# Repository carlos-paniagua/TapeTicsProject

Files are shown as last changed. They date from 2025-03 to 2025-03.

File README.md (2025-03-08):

# Tape-Tics: A Flexible and Modular Vibrotactile Feedback System for Rapid Prototyping
Carlos Paniagua, Hiroki Ota, Yutaro Hirao, Monica Perusquia-Hernandez, Hideaki Uchiyama, Kiyoshi Kiyokawa

This repository contains the hardware and software design files for TapeTics

## Content
Hardware/ -  Circuit Information \
src/ - Source code open with platformIO \
GUI/ - GUI controller using Max8 

## Software Version Information
1. Arduino IDE 2.3.2\
   Queue 2,0\
   NimBLE-Arduino 1.4.2\
   FastLED 3.7.3\
   M5Atom 0.1.2\
   M5Stack 2.1.1\
   ArxContainer 0.7.0\
   IRremote 4.4.1\
   ArduinoOSC 0.5.1\
   MAX30100lib 1.2.1
2. Max 8.6.4
3. Python 3.12\
   Bleak \
   pythonosc
4. VScode
5. PlatfromIO

## Component list

| Parts | Quantity | Value | Cost  ($) |
|:---|---:|:---|---:|
| Chip Capacitor 0.1μf |3 | [CC0603KRX7R9BB104](https://jlcpcb.com/partdetail/Yageo-CC0603KRX7R9BB104/C14663)  |0.0063|
| Chip Capacitor 10μf|2 | [CL10A106KP8NNNC](https://jlcpcb.com/partdetail/20411-CL10A106KP8NNNC/C19702) |0.01|
| Diode|1 | [1N4001W](https://jlcpcb.com/partdetail/Yongyutai-1N4001W/C2944152)|0.0052|
| RGB-LED  |  1 | [WS2812B-V5/W](https://jlcpcb.com/partdetail/Worldsemi-WS2812B_V5W/C2874885) |0.0762|
| Neopixel IC| 1 | [WS2811](https://jlcpcb.com/partdetail/Worldsemi-WS2811/C114581) |0.033|
| Vibrating Motor|1 | [LCM1027A2445F](https://jlcpcb.com/partdetail/Leader-LCM1027A2445F/C2759984) |0.30|
| Chip Resistor 33Ω| 2 | [0603WAF330JT5E](https://jlcpcb.com/partdetail/23867-0603WAF330JT5E/C23140) |0.002|
| Chip Resistor 100Ω |  1 | [0603WAF1000T5E](https://jlcpcb.com/partdetail/23502-0603WAF1000T5E/C22775) |0.001 |
| Photocoupler |1 | [TLP627(TP1,F)](https://jlcpcb.com/partdetail/Toshiba-TLP627_TP1_F/C30336) | 0.48 |
| Voltage Regulator 16V to 5V| 1 | [SPX3819M5-L-5-0/TR](https://jlcpcb.com/partdetail/MaxLinear-SPX3819M5_L_5_0TR/C13417) |0.1463|
| Voltage Regulator 16V to 3.3V  |1 | [SPX3819M5-L-3-3/TR](https://jlcpcb.com/partdetail/Maxlinear-SPX3819M5_L_3_3TR/C9055) |0.0828|

## Presented Conferences
[MVE 2024](https://ken.ieice.org/ken/paper/20240315DcCd/)\
[VRSJ 2024](https://conference.vrsj.org/ac2024/program/doc/1G-23.pdf)\
[IEEE VR 2025](https://ieeevr.org/2025/program/posters/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)\
[AHs 2025](https://augmented-humans.org/program/)

## Teaser Video (IEEE VR 2025)
youtube (https://youtu.be/rIjlwakAgLE)

## Aknowledgements
[Nara Institute of Science and Technology](https://www.naist.jp/en/)\
[Cybernetics and Reality Engineering (CARE) Laboratory](https://carelab.info/en/)\
Hiroki Ota\
Yutaro Hirao\
Monica Perusquia-Hernandez\
Hideaki Uchiyama\
Kiyoshi Kiyokawa

naist

care

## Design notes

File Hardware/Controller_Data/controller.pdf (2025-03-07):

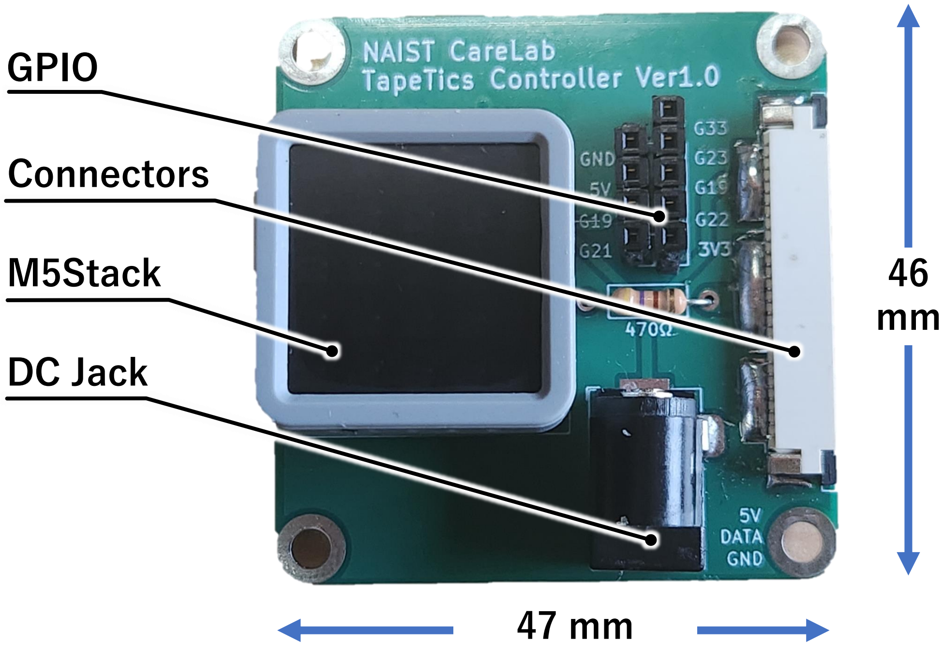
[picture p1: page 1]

46
mm

### 47 mm

Connectors

GPIO

M5Stack

DC Jack

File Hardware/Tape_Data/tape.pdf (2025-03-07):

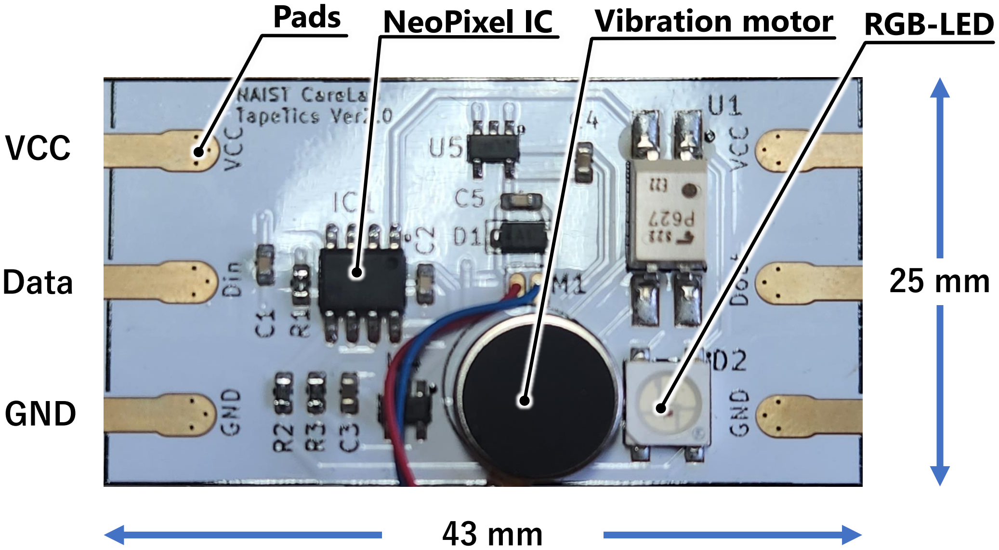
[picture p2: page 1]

Data

VCC

GND

### 25 mm

### 43 mm

Pads | NeoPixel IC | Vibration motor RGB-LED

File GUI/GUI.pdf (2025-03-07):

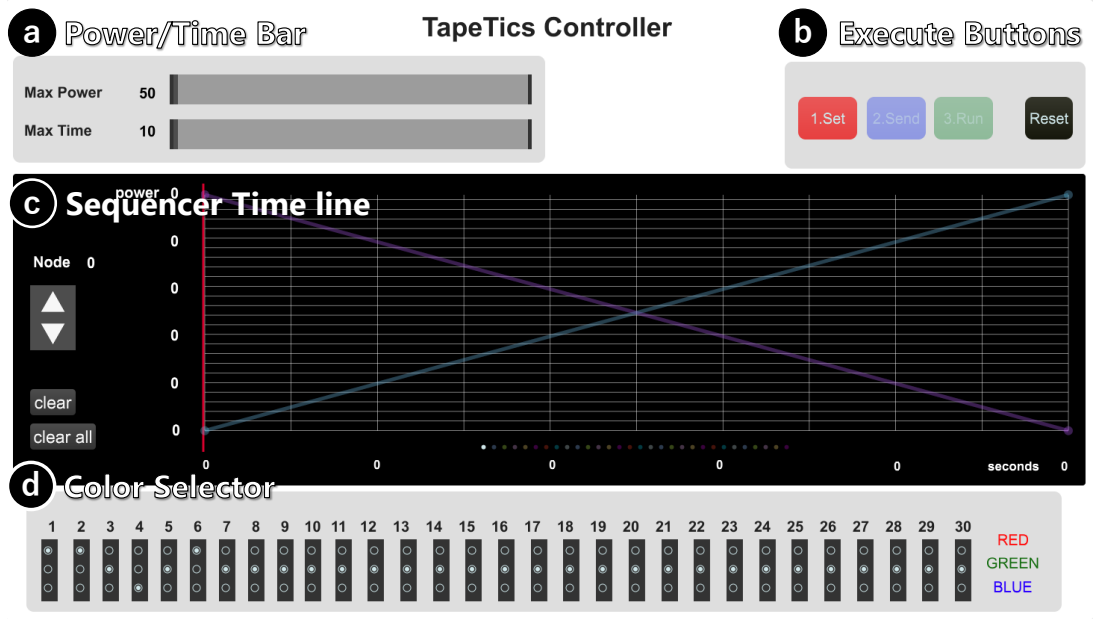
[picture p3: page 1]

Sequencer Time line

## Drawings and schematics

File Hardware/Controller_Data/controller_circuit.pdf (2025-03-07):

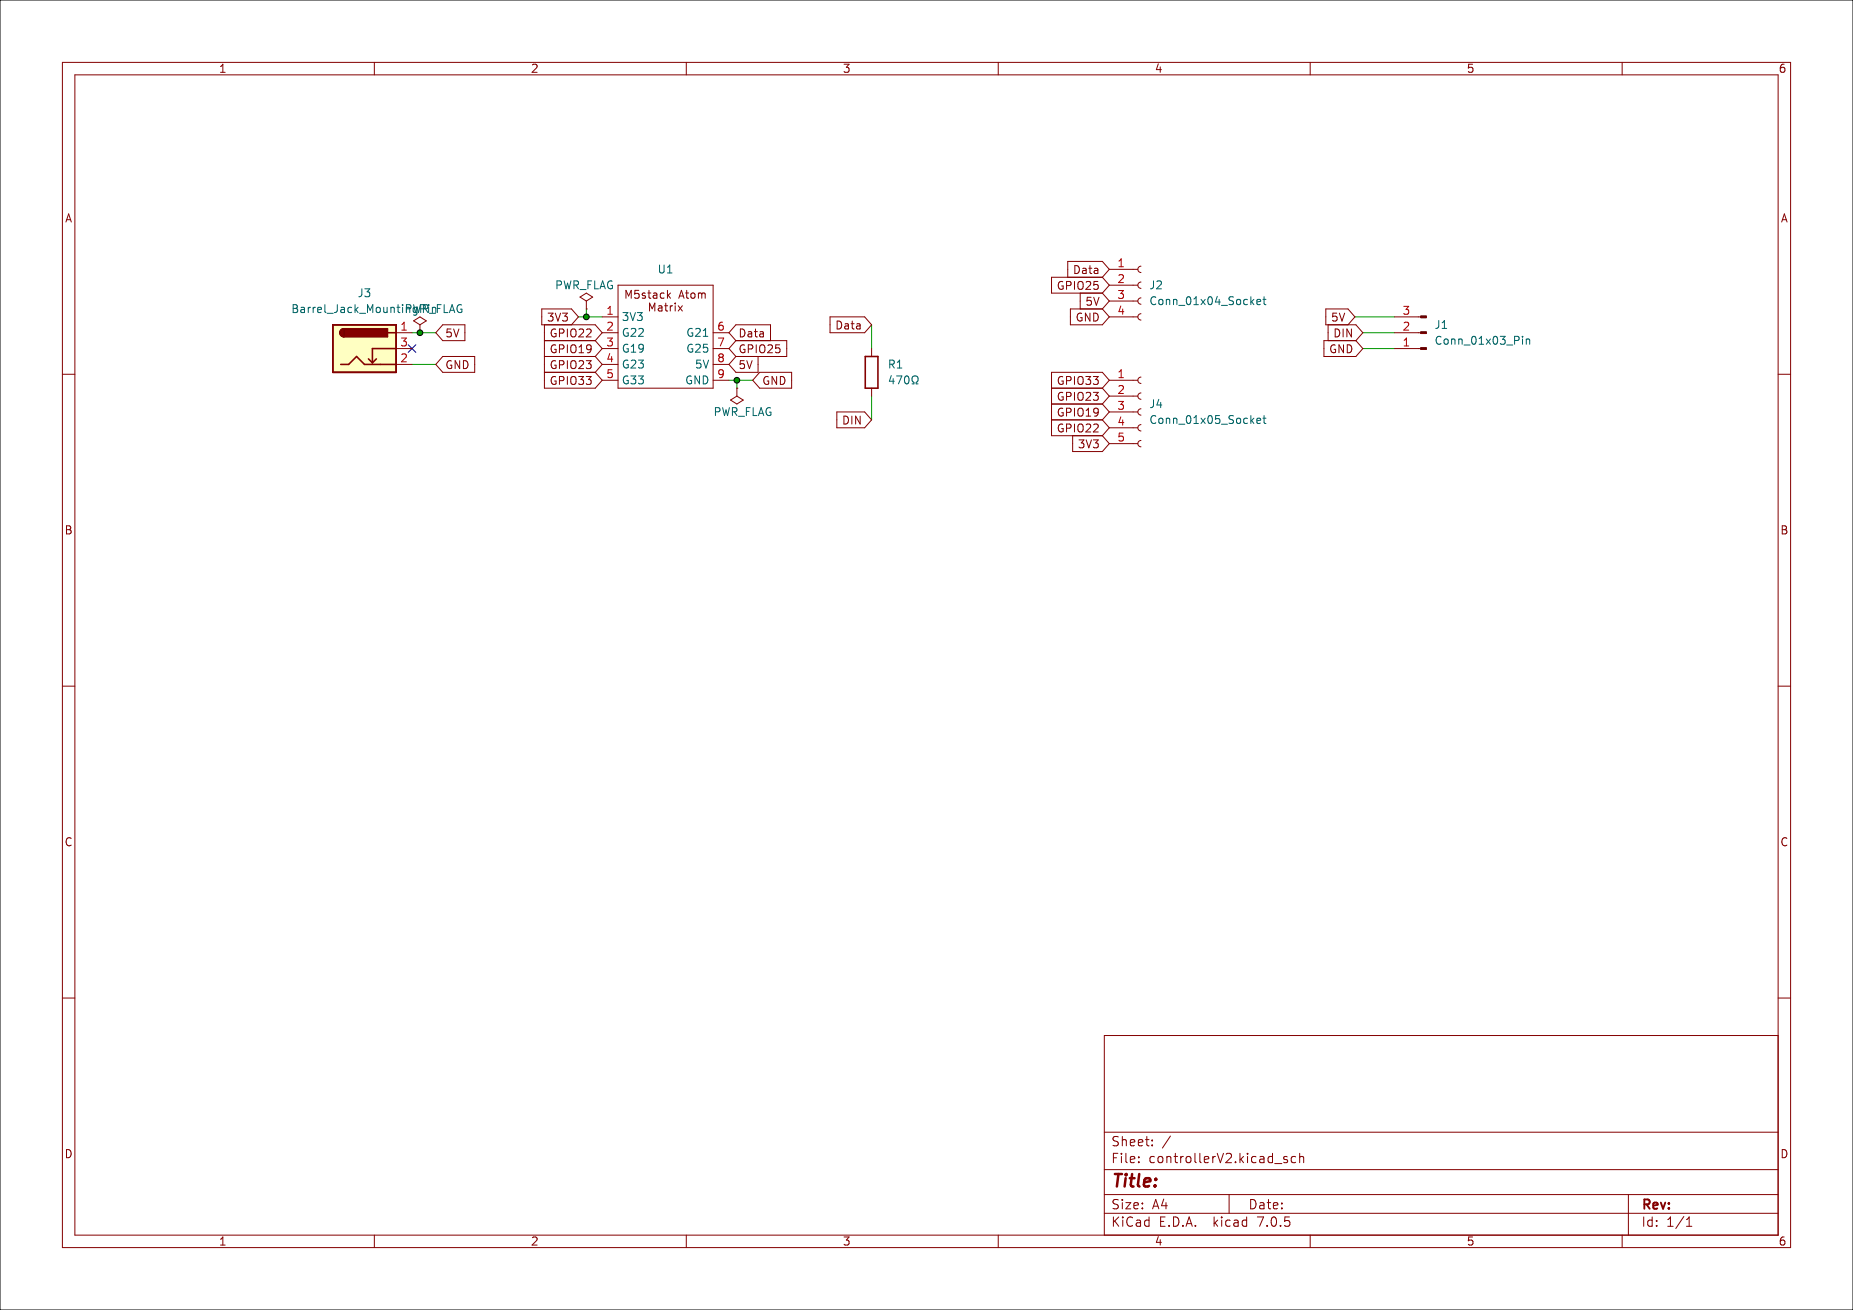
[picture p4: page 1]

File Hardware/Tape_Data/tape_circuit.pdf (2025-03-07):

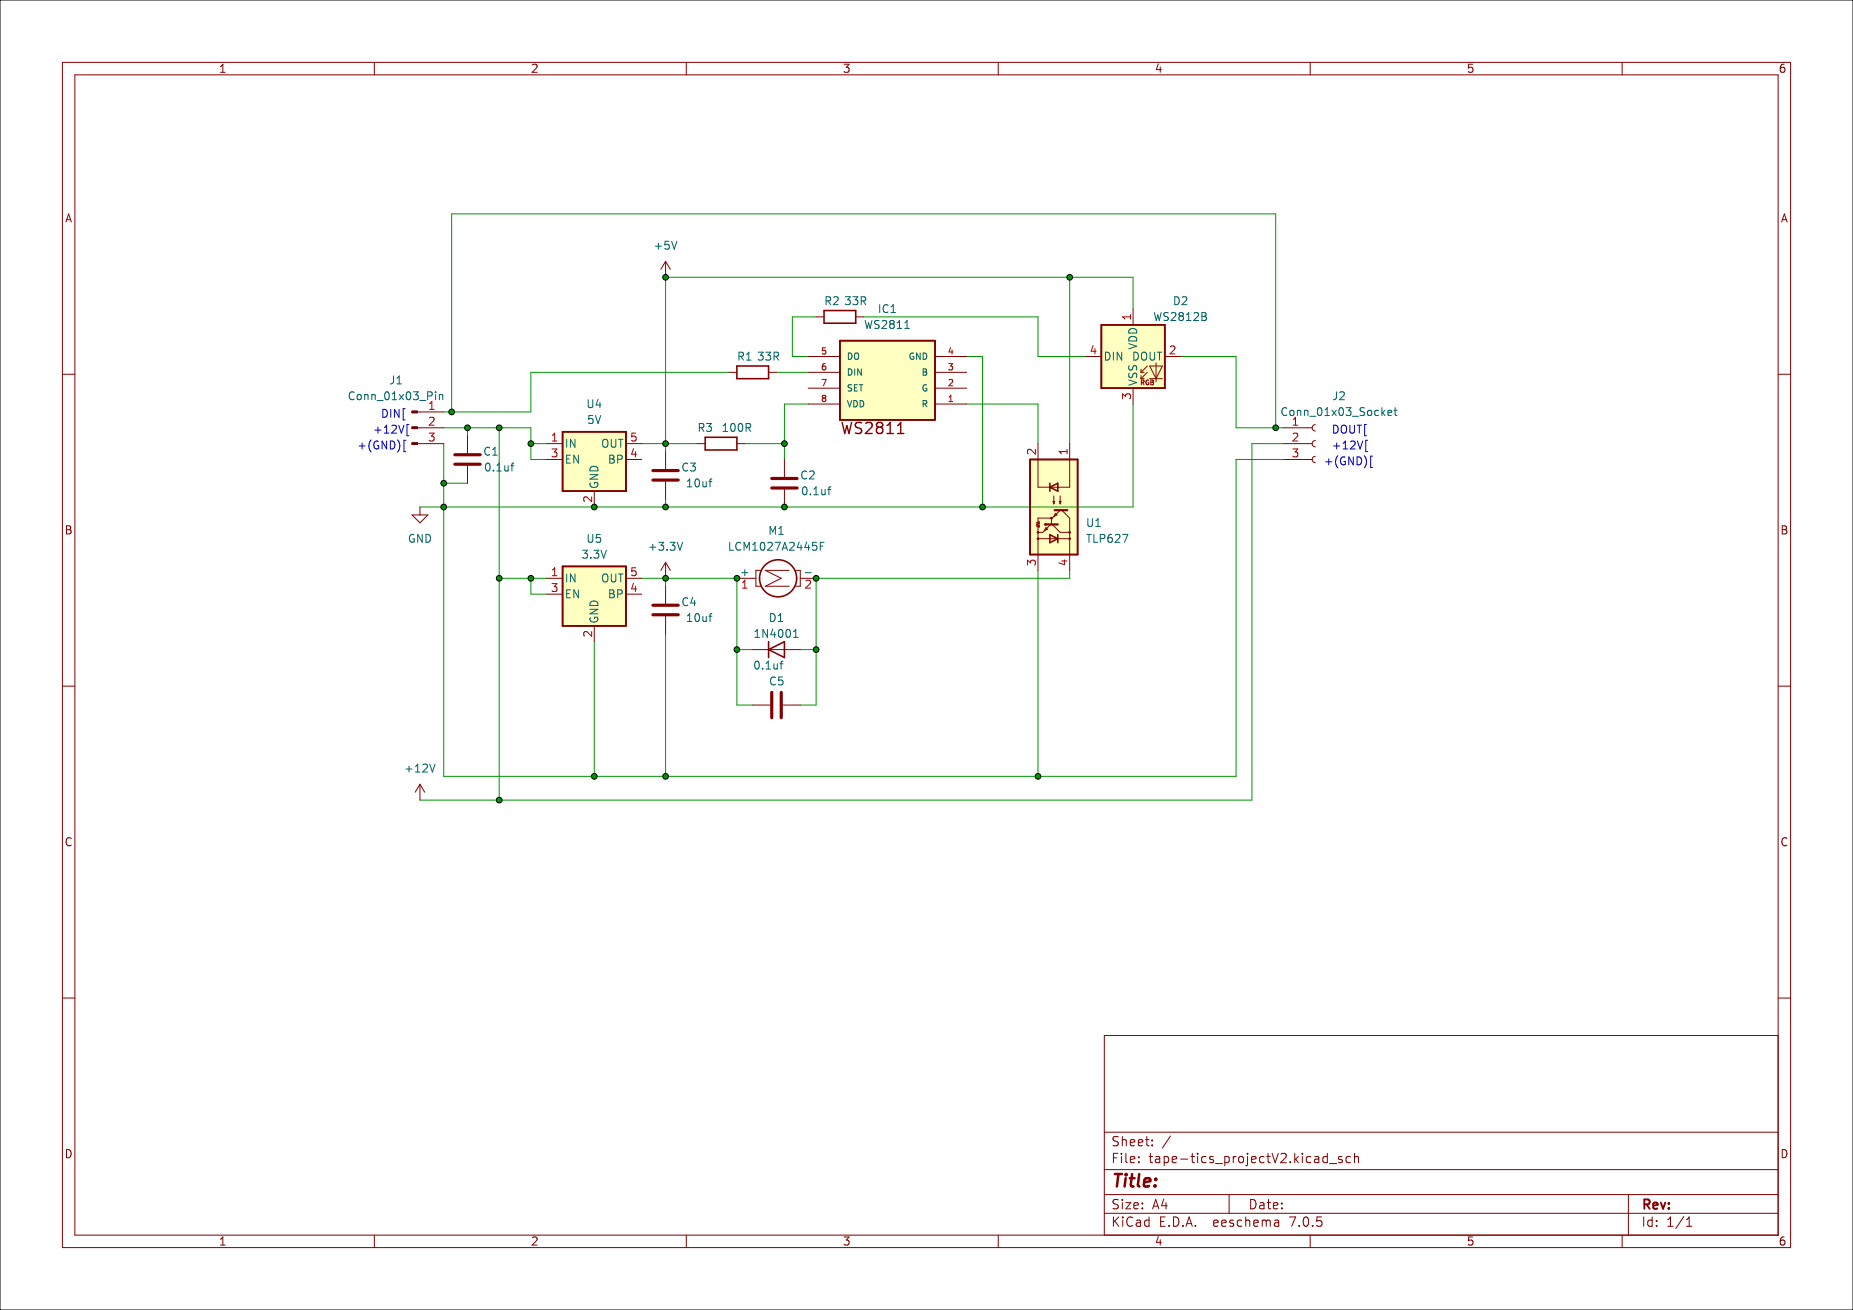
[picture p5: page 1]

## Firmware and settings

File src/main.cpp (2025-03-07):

#include <M5Atom.h>

#define USE_BLE
// #define USE_OSC

// #define DEVICE_TEST
// #ifdef DEVICE_TEST_2

// #deifne USE_OTHER_FUNCTIONS
#define USE_SERIAL_COMMAND
// #define SOUND_MODE
// #define IR_MODE
// #define MUSCLE_MODE
// #define HEART_MODE

int preset_time = 10000;
int steps = 0;

void ledOnSingle(int i);
void ledOn();
String getSerialCommand();

void addMessageToQueue(String command);
void processQueueTask(void *pvParameters);

#ifdef USE_BLE
void handleBLECommand(std::string value);
void processBLETask(void *pvParameters);
#endif // USE_BLE

void setRGB(String s);
void setAllRGB(String s);
void printRGB();

#ifdef IR_MODE
#include <IRremote.h>
int receiverPin = 32;
void IRsensor();
void handleIRCommand(unsigned long command);
#endif

#ifdef MUSCLE_MODE
int EMG_PIN = 33;    // GPIO pin where MyoWare 2.0 sensor is connected
// int THRESHOLD = 500; // Threshold value to detect muscle contraction
void MuscleMode();
#endif

#ifdef HEART_MODE
#include "MAX30100.h"
#define SAMPLING_RATE   (MAX30100_SAMPRATE_100HZ)
#define IR_LED_CURRENT  (MAX30100_LED_CURR_24MA)
#define RED_LED_CURRENT (MAX30100_LED_CURR_27_1MA)
#define PULSE_WIDTH     (MAX30100_SPC_PW_1600US_16BITS)
#define HIGHRES_MODE    (false)
MAX30100 sensor; 
void HeartMode();
#endif

// 追加関数
#ifdef USE_OTHER_FUNCTIONS
void initializeHBM();
void SoundMode();
void shake();
void MuscleMode();
void HeartBeatMode();
void onBeatDetected();
#endif

// アニメーション
void waveAnimation();
void randomAnimation();
void shockAnimation();

// メッセージキューの定義
////////////////////////////////////////////////////////////////////
#include <cppQueue.h>

cppQueue messageQueue(sizeof(String), 1000, FIFO, false); // FIFOキューの初期化

// LED
///////////////////////////////////////////////////////////////////////
#include <FastLED.h>
#include <Wire.h>

#define PIN 22
#define NUMMAX 60
#define NUMSETS 20
#define NUMPIXELS (NUMMAX * 2)
#define LED_TYPE WS2812
#define COLOR_ORDER RGB
#define BRIGHTNESS 255

#define LED_COLOR_GREEN (0x001B00)  // LEDのカラーコード 緑
#define LED_COLOR_RED (0xff0000)    // LEDのカラーコード 赤
#define LED_COLOR_YELLOW (0xffff00) // LEDのカラーコード 赤
#define LED_COLOR_OFF (0x000000)    // LEDのカラーコード 黒

CRGB leds[NUMPIXELS];
int power[NUMMAX]; // セットごとのパワーの配列
int red[NUMMAX];   // セットごとの赤の配列
int green[NUMMAX]; // セットごとの緑の配列
int blue[NUMMAX];  // セットごとの青の配列

bool startExecution = false; // ボタンが押されたら true になる

CRGB getPixelColor1(uint8_t power)
{
  return CRGB(power, 0, 0);
}

CRGB getPixelColor2(uint8_t red, uint8_t green, uint8_t blue)
{
  return CRGB(green, red, blue);
}

#ifdef DEVICE_TEST
// デバイス単体試験用変数
float accX, accY, accZ;

// データ収集用
const int sampleRate = 5;  // サンプリング周期 (ms)
const int duration = 5000; // 測定時間 (ms)
const int numSamples = duration / sampleRate;

float accXData[numSamples];
float accYData[numSamples];
float accZData[numSamples];
// RMS値を計算する関数
float calculateRMS(float *data, int size)
{
  float sum = 0;
  for (int i = 0; i < size; i++)
  {
    sum += data[i] * data[i];
  }
  return sqrt(sum / size);
}

#endif

// BLE
///////////////////////////////////////////////////////////////////////
#ifdef USE_BLE
#include <BLEDevice.h>
#include <BLEUtils.h>
#include <BLEServer.h>
#include <BLE2902.h>

String SERVICE_UUID = "12345678-1234-5678-1234-56789abcdef0";        // サービスUUIDのデフォルト値
String CHARACTERISTIC_UUID = "abcdef12-3456-7890-abcd-ef1234567890"; // キャラクタリスティックUUIDのデフォルト値
String BLE_DEVICE_NAME = "Tapetics_Controller";                      // BLEデバイス名のデフォルト値

BLEServer *pServer = NULL;
BLECharacteristic *pCharacteristic = NULL;
bool deviceConnected = false;

class MyServerCallbacks : public BLEServerCallbacks
{
  void onConnect(BLEServer *pServer) override
  {
    Serial.println("Client connected");
    deviceConnected = true;
    if (deviceConnected)
    {
      M5.dis.fillpix(LED_COLOR_GREEN);
    }
  }
  void onDisconnect(BLEServer *pServer) override
  {
    Serial.println("Client disconnected");
    deviceConnected = false;
    BLEDevice::startAdvertising();
    M5.dis.fillpix(LED_COLOR_RED);
  }
};

void sendDataOverBLE(const char *data)
{
  if (deviceConnected && pCharacteristic != NULL)
  {
    pCharacteristic->setValue(data);
    pCharacteristic->notify();
  }
}

void initializeBLE()
{
  BLEDevice::init(BLE_DEVICE_NAME.c_str());

  pServer = BLEDevice::createServer();
  pServer->setCallbacks(new MyServerCallbacks());
  BLEService *pService = pServer->createService(SERVICE_UUID.c_str());

  pCharacteristic = pService->createCharacteristic(
      CHARACTERISTIC_UUID.c_str(),
      BLECharacteristic::PROPERTY_READ |
          BLECharacteristic::PROPERTY_WRITE |
          BLECharacteristic::PROPERTY_NOTIFY |
          BLECharacteristic::PROPERTY_INDICATE);
  pCharacteristic->addDescriptor(new BLE2902());

  pService->start();

  BLEAdvertising *pAdvertising = BLEDevice::getAdvertising();
  pAdvertising->addServiceUUID(SERVICE_UUID.c_str());
  pAdvertising->setScanResponse(true);
  pAdvertising->setMinPreferred(0x12);

  BLEDevice::startAdvertising();

  Serial.println("BLE initialize complete");

  M5.dis.fillpix(LED_COLOR_RED);
}

#endif // USE_BLE

// OSC
///////////////////////////////////////////////////////////////////////
#ifdef USE_OSC
#include <ArduinoOSCWiFi.h>

const char *ssid = "ssid";      // WiFi SSIDを設定
const char *password = "password";   // WiFi パスワードを設定
const IPAddress ip(192, 168, 11, 43);     // デバイスの固定IPアドレス(M5stackのIP)
const IPAddress gateway(192, 168, 11, 1); // ゲートウェイのIPアドレス(ルーターのIP)
const IPAddress subnet(255, 255, 255, 0); // サブネットマスク

// const char *host = "192.168.11.3"; // 送信先のホストIPアドレス(QuestのIP)
const int recv_port = 8001; // 受信ポート番号(M5Stackが受信するポート番号)
// const int send_port = 9001;        // 送信ポート番号

void initializeWifi()
{
  WiFi.disconnect(true, true); // WiFiを無効にしてAP情報を消去
  delay(200);
  WiFi.begin(ssid, password); // WiFiに接続
  delay(200);
  WiFi.config(ip, gateway, subnet); // 固定IPを設定
  delay(200);

  // WiFi接続待ち
  while (WiFi.status() != WL_CONNECTED)
  {
    delay(500);
  }
  Serial.println("WiFi connected"); // WiFi接続成功メッセージ
  Serial.print("WiFi connected, IP = ");
  Serial.println(WiFi.localIP());
  // M5.dis.fillpix(LED_COLOR_YELLOW);
}

void initializeOSC()
{
  // /fingerアドレスに対してサブスクライブ（OSCメッセージ受信の設定）
  OscWiFi.subscribe(recv_port, "/finger", [](const OscMessage &msg){
  String s = msg.getArgAsString(0);

  Serial.println(s);

  int setIndex, pwr, r, g, b;
  int commaIndex = 0;
  int startIdx = 0;
  int commaIdx = s.indexOf(',');

  setIndex = s.substring(startIdx, commaIdx).toInt() - 1;
  startIdx = commaIdx + 1;
  commaIdx = s.indexOf(',', startIdx);
  // 2. pwr
  power[setIndex] = s.substring(startIdx, commaIdx).toInt();
  startIdx = commaIdx + 1;
  commaIdx = s.indexOf(',', startIdx);
  // 3. r
  red[setIndex] = s.substring(startIdx, commaIdx).toInt();
  startIdx = commaIdx + 1;
  commaIdx = s.indexOf(',', startIdx);
  // 4. g
  green[setIndex] = s.substring(startIdx, commaIdx).toInt();
  startIdx = commaIdx + 1;
  commaIdx = s.indexOf(',', startIdx);
  // 5. b
  blue[setIndex] = s.substring(startIdx, commaIdx).toInt();
  startIdx = commaIdx + 1;
  ledOnSingle(setIndex); });
}
#endif // USE_OSC

// メイン処理
///////////////////////////////////////////////////////////////////////////
void setup()
{
  M5.begin(true, false, true); // 本体初期化（UART, I2C, LED）
  M5.IMU.Init();               // IMUを使うとき解除

#ifdef HEART_MODE
  sensor.begin();
#endif

  FastLED.addLeds<LED_TYPE, PIN, COLOR_ORDER>(leds, NUMMAX).setCorrection(TypicalLEDStrip);
  FastLED.setDither(DISABLE_DITHER);

#ifdef USE_BLE
  initializeBLE();
  xTaskCreatePinnedToCore(processBLETask, "BLETask", 4096, NULL, 1, NULL, 1);
#endif // USE_BLE

#ifdef USE_OSC
  initializeWifi();
  initializeOSC();
#endif // USE_OSC

#ifdef IR_MODE
  IrReceiver.begin(receiverPin, true);
#endif

#ifdef DEVICE_TEST_2
  delay(10000);
  Serial.println("Start in 3 sec");
  delay(3000);

  for (int l = 50; l < 256; l = l + 10)
  {
    String rgbCommand = String(l) + String(",0,0,0");
    // String rgbCommand = String("255,0,0,0");
    setAllRGB(rgbCommand);
    delay(3000);

    float rmsAllValues[5]; // 5回分のRMS_Allを保存
    float rmsAllSum = 0.0; // RMS_Allの合計値（平均計算用）

    //  データ収集
    for (int i = 0; i < 5; i++)
    {
      memset(accXData, 0, sizeof(accXData));
      memset(accYData, 0, sizeof(accYData));
      memset(accZData, 0, sizeof(accZData));

      for (int j = 0; j < numSamples; j++)
      {
        M5.IMU.getAccelData(&accX, &accY, &accZ);

        // データを保存
        accXData[j] = accX;
        accYData[j] = accY;
        accZData[j] = accZ;
        delay(sampleRate); // サンプリング間隔
      }

      // RMS値の計算
      // Serial.println("データ収集完了！RMS値を計算します...");
      float rmsX = calculateRMS(accXData, numSamples);
      float rmsY = calculateRMS(accYData, numSamples);
      float rmsZ = calculateRMS(accZData, numSamples);
      float rmsAll = sqrt((rmsX * rmsX) + (rmsY * rmsY) + (rmsZ * rmsZ));

      rmsAllValues[i] = rmsAll;
      rmsAllSum += rmsAll;

      delay(1000);
    }
    // 平均RMSを計算
    float rmsAllAverage = rmsAllSum / 5.0;
    float ms = rmsAllAverage * 9.81;

    // シリアルに結果を送信 (指定形式)
    Serial.printf("%d, %.3f, %.3f, %.3f, %.3f, %.3f, %.3f, %.3f\n",
                  l, rmsAllValues[0], rmsAllValues[1], rmsAllValues[2], rmsAllValues[3], rmsAllValues[4], rmsAllAverage, ms);
    setAllRGB("0,0,0,0");
    delay(2000); // 次のPWM値に進む前に少し待つ
  }
#endif

  // キュー処理タスクを起動
  xTaskCreatePinnedToCore(processQueueTask, "QueueTask", 4096, NULL, 1, NULL, 0);
  Serial.println("Initialize complete");
}

void loop()
{
  M5.update();

#ifdef USE_OSC
  OscWiFi.update();
#endif

#ifdef USE_SERIAL_COMMAND
  if (Serial.available() > 0)
  {
    String s = getSerialCommand();
    if (s.length() > 0) // 空のメッセージを無視
    {
      if (s == "run")
      {
        if (!startExecution) // 初回のみ出力
        {
          startExecution = true;
          // Serial.println("Starting execution of queued messages.");
        }
      }
      else if (s == "wave" || s == "shock" || s == "random" || s == "ir" || s == "muscle" || s == "heart")
      {
        setRGB(s);
      }
      else
      {
        Serial.println(s);

        int setIndex, pwr, r, g, b;
        // メッセージをカンマで分割
        int commaIndex = 0;
        String parameters[5]; // 6つのパラメータを期待
        // String remaining = *msg;
        int startIdx = 0;
        int commaIdx = s.indexOf(',');
        setIndex = s.substring(startIdx, commaIdx).toInt() - 1;
        startIdx = commaIdx + 1;
        commaIdx = s.indexOf(',', startIdx);
        // 2. pwr
        power[setIndex] = s.substring(startIdx, commaIdx).toInt();
        startIdx = commaIdx + 1;
        commaIdx = s.indexOf(',', startIdx);
        // 3. r
        red[setIndex] = s.substring(startIdx, commaIdx).toInt();
        startIdx = commaIdx + 1;
        commaIdx = s.indexOf(',', startIdx);
        // 4. g
        green[setIndex] = s.substring(startIdx, commaIdx).toInt();
        startIdx = commaIdx + 1;
        commaIdx = s.indexOf(',', startIdx);
        // 5. b
        blue[setIndex] = s.substring(startIdx, commaIdx).toInt();
        startIdx = commaIdx + 1;
        ledOnSingle(setIndex);

#ifdef DEVICE_TEST
        Serial.println("start");
        ledOnSingle(setIndex);
        delay(3000);

        float rmsAllValues[5]; // 5回分のRMS_Allを保存
        float rmsAllSum = 0.0; // RMS_Allの合計値（平均計算用）

        //  データ収集
        for (int i = 0; i < 5; i++)
        {
          memset(accXData, 0, sizeof(accXData));
          memset(accYData, 0, sizeof(accYData));
          memset(accZData, 0, sizeof(accZData));

          for (int j = 0; j < numSamples; j++)
          {
            M5.IMU.getAccelData(&accX, &accY, &accZ);

            // データを保存
            accXData[j] = accX;
            accYData[j] = accY;
            accZData[j] = accZ;
            delay(sampleRate); // サンプリング間隔
          }

          // RMS値の計算
          Serial.println("データ収集完了！RMS値を計算します...");
          float rmsX = calculateRMS(accXData, numSamples);
          float rmsY = calculateRMS(accYData, numSamples);
          float rmsZ = calculateRMS(accZData, numSamples);
          float rmsAll = sqrt((rmsX * rmsX) + (rmsY * rmsY) + (rmsZ * rmsZ));

          rmsAllValues[i] = rmsAll;
          rmsAllSum += rmsAll;

          delay(1000);
        }
        // 平均RMSを計算
        float rmsAllAverage = rmsAllSum / 5.0;
        float ms = rmsAllAverage * 9.81;

        // シリアルに結果を送信 (指定形式)
        Serial.printf("%.3f, %.3f, %.3f, %.3f, %.3f, %.3f, %.3f\n",
                      rmsAllValues[0], rmsAllValues[1], rmsAllValues[2], rmsAllValues[3], rmsAllValues[4], rmsAllAverage, ms);
        setAllRGB("0,0,0,0");
        delay(2000); // 次のPWM値に進む前に少し待つ
#endif
      }
    }
  }
#endif

#ifdef IR_MODE
  if (IrReceiver.decode())
  {
    IrReceiver.printIRResultShort(&Serial);
    if (IrReceiver.decodedIRData.decodedRawData == 0xBA45FF00)
    {
      Serial.println("IR Mode");
      IrReceiver.resume();
      IRsensor();
    }
    IrReceiver.resume();
  }

#endif
}

#ifdef USE_BLE
void handleBLECommand(std::string value)
{
  String command = String(value.c_str());
  if (command == "run")
  {
    startExecution = true;
    Serial.println("Starting execution of queued messages.");
  }
  else if (command == "endSend")
  {
    Serial.print("Queue count after endSend: ");
    Serial.println(messageQueue.getCount());
  }
  else if (command == "wave" || command == "shock" || command == "random")
  {
    setRGB(command);
  }
  else
  {
    addMessageToQueue(command);

#ifdef DEVICE_TEST
    // Latency Measurement
    String s = command;
    int setIndex, pwr, r, g, b;
    // メッセージをカンマで分割
    int commaIndex = 0;
    String parameters[5]; // 6つのパラメータを期待
    // String remaining = *msg;
    int startIdx = 0;
    int commaIdx = s.indexOf(',');

    setIndex = s.substring(startIdx, commaIdx).toInt() - 1;
    startIdx = commaIdx + 1;
    commaIdx = s.indexOf(',', startIdx);

    // 2. pwr
    power[setIndex] = s.substring(startIdx, commaIdx).toInt();
    startIdx = commaIdx + 1;
    commaIdx = s.indexOf(',', startIdx);

    // 3. r
    red[setIndex] = s.substring(startIdx, commaIdx).toInt();
    startIdx = commaIdx + 1;
    commaIdx = s.indexOf(',', startIdx);

    // 4. g
    green[setIndex] = s.substring(startIdx, commaIdx).toInt();
    startIdx = commaIdx + 1;
    commaIdx = s.indexOf(',', startIdx);

    // 5. b
    blue[setIndex] = s.substring(startIdx, commaIdx).toInt();
    startIdx = commaIdx + 1;

    ledOnSingle(setIndex);
#endif // DEVICE_TEST
  }
}
#endif // USE_BLE

void addMessageToQueue(String command)
{
  if (!messageQueue.isFull())
  {
    String strValue = String(command.c_str());
    int startIndex = 0;
    int endIndex = strValue.indexOf('\n');
    while (endIndex != -1)
    {
      String line = strValue.substring(startIndex, endIndex);
      String *msg = new String(line);
      messageQueue.push(&msg);
      // Serial.print(messageQueue.getCount());
      // Serial.print("  Queued message: ");
      // Serial.println(line);
      startIndex = endIndex + 1;
      endIndex = strValue.indexOf('\n', startIndex);
    }
  }
  else
  {
    Serial.println("Warning: Queue is full! Unable to queue more messages.");
  }
}

void processQueueTask(void *pvParameters)
{
  while (true)
  {
    if (startExecution) // ボタンが押されたらキュー処理を開始
    {
      String *msg = nullptr;
      if (messageQueue.pop(&msg) && msg != nullptr)
      {
        Serial.print(messageQueue.getCount());
        Serial.print(": pop from queue :");
        Serial.println(*msg);
        String s = *msg;
        if (s == "delay")
        {
          vTaskDelay(100 / portTICK_PERIOD_MS);
        }
        else
        {
          bool validFormat = true;
          int setIndex, pwr, r, g, b;
          // メッセージをカンマで分割
          int commaIndex = 0;
          String parameters[5]; // 6つのパラメータを期待
          // String remaining = *msg;
          int startIdx = 0;
          int commaIdx = s.indexOf(',');
          setIndex = s.substring(startIdx, commaIdx).toInt() - 1;
          startIdx = commaIdx + 1;
          commaIdx = s.indexOf(',', startIdx);
          // 2. pwr
          power[setIndex] = s.substring(startIdx, commaIdx).toInt();
          startIdx = commaIdx + 1;
          commaIdx = s.indexOf(',', startIdx);
          // 3. r
          red[setIndex] = s.substring(startIdx, commaIdx).toInt();
          startIdx = commaIdx + 1;
          commaIdx = s.indexOf(',', startIdx);
          // 4. g
          green[setIndex] = s.substring(startIdx, commaIdx).toInt();
          startIdx = commaIdx + 1;
          commaIdx = s.indexOf(',', startIdx);
          // 5. b
          blue[setIndex] = s.substring(startIdx, commaIdx).toInt();
          startIdx = commaIdx + 1;
          ledOnSingle(setIndex);
          delete msg;
        }
      }
      else
      {
        Serial.println("Error: Failed to pop message from queue.");
      }
    }
    // すべてのメッセージが処理されているか確認
    if (messageQueue.getCount() == 0 && startExecution)
    {
      setAllRGB("0,0,0,0,0"); // RGBをリセット
      Serial.println("All messages processed. FINISH");
      startExecution = false;
    }
    vTaskDelay(2 / portTICK_PERIOD_MS); // 少し待機してループを繰り返す
  }
}

#ifdef USE_BLE
void processBLETask(void *pvParameters)
{
  while (true)
  {
    // BLE処理を実行
    if (deviceConnected)
    {
      std::string value = pCharacteristic->getValue();
      if (!value.empty())
      {
        handleBLECommand(value);
        // BandWidth Measurement
        //  unsigned long currentMillis = millis(); // 受信時刻を取得
        //  Serial.printf("Received command at: %lu ms\n", currentMillis);
        pCharacteristic->setValue("");
      }
    }
    vTaskDelay(1 / portTICK_PERIOD_MS); // 少し待機してループを繰り返す
  }
}
#endif // USE_BLE

void ledOnSingle(int i)
{
  leds[i * 2] = getPixelColor1(power[i]);
  leds[i * 2 + 1] = getPixelColor2(red[i], green[i], blue[i]);

  FastLED.setBrightness(BRIGHTNESS);
  FastLED.show();
}

void ledOn()
{
  for (int i = 0; i < NUMSETS; i++)
  {
    leds[i * 2] = getPixelColor1(power[i]);
    leds[i * 2 + 1] = getPixelColor2(red[i], green[i], blue[i]);
  }

  FastLED.setBrightness(BRIGHTNESS);
  FastLED.show();
}

#ifdef USE_SERIAL_COMMAND
String getSerialCommand()
{
  String s = "";
  while (Serial.available() > 0)
  {
    char c = Serial.read();
    if (c == '\n' || c == '\r')
    {
      break; // 改行が来たら終了
    }
    s += c;
  }
  s.trim();
  return s;
}
#endif // USE_SERIAL_COMMAND

void setRGB(String s)
{
  if (s.startsWith("all"))
  {
    setAllRGB(s.substring(4));
  }
  else if (s.startsWith("wave"))
  {
    Serial.println("Wave Mode");
    waveAnimation();
  }
  else if (s.startsWith("shock"))
  {
    Serial.println("Shock Mode");
    shockAnimation();
  }
  else if (s.startsWith("random"))
  {
    Serial.println("Random Mode");
    randomAnimation();
  }
#ifdef IR_MODE
  else if (s.startsWith("ir"))
  {
    Serial.println("IR Mode");
    IRsensor();
  }
#endif

#ifdef MUSCLE_MODE
  else if (s.startsWith("muscle"))
  {
    Serial.println("Muscle mode");
    MuscleMode();
  }
#endif

#ifdef HEART_MODE
  else if (s.startsWith("heart"))
  {
    Serial.println("Heart mode");
    HeartMode();
  }
#endif
}

void setAllRGB(String s)
{
  int pwr, r, g, b;
  sscanf(s.c_str(), "%d,%d,%d,%d", &pwr, &r, &g, &b);
  for (int i = 0; i < NUMSETS; i++)
  {
    power[i] = pwr;
    red[i] = r;
    green[i] = g;
    blue[i] = b;
  }

  ledOn(); // ここにledonを入れないと起動しない
}

void printRGB()
{
  Serial.println("--------------------------------------");
  for (int i = 0; i < NUMSETS; i++)
  {
    Serial.printf("(Set %d, Power, R, G, B) = (%d, %d, %d, %d)\n", i + 1, power[i], red[i], green[i], blue[i]);
  }
}

#ifdef SOUND_MODE
void SoundMode()
{
  M5.dis.fillpix(LED_COLOR_YELLOW);
  int max_value = 50; // Maximum value for red, green, blue, power
  int value = 255;
  int nodeval = value / NUMSETS;
  int scaled_nodeval = max_value / NUMSETS; // Scaled nodeval

  while (true)
  {
    if (deviceConnected)
    {
      std::string command = pCharacteristic->getValue();
      if (command == "end")
      {
        break;
      }
      else if (command.length() >= 2)
      {
        int amplitude = std::stoi(command); // 修正箇所
        if (amplitude >= 0 && amplitude <= value)
        {
          int scaled_amplitude = (amplitude * max_value) / value; // Scale amplitude to 0-50 range
          int red = 0, green = 0, blue = 0;

          if (amplitude <= 150)
          {
            green = scaled_amplitude; // Set green to max value 50
          }
          else if (amplitude <= 200)
          {
            red = scaled_amplitude;
            green = scaled_amplitude; // Set yellow to max value 50
          }
          else
          {
            red = scaled_amplitude; // Set red to max value 50
          }

          String colorCommand = String(scaled_amplitude) + "," + String(red) + "," + String(green) + "," + String(blue) + "," + String(0);
          setAllRGB(colorCommand);
        }
      }
      // ledOn();
    }
  }
  Serial.println("End SoundMode");
  setAllRGB("0,0,0,0,0");
  M5.dis.fillpix(LED_COLOR_GREEN);
}
#endif

#ifdef IR_MODE
void IRsensor()
{
  M5.dis.fillpix(LED_COLOR_YELLOW);
  bool flag = true;
  while (flag)
  {
    if (IrReceiver.decode())
    {
      IrReceiver.printIRResultShort(&Serial);
      if (IrReceiver.decodedIRData.decodedRawData == 0xBA45FF00)
      {
        flag = false;
      }
      else
      {
        handleIRCommand(IrReceiver.decodedIRData.decodedRawData);
      }
    }
  }
  IrReceiver.resume();
  Serial.println("End IR mode");
  M5.dis.fillpix(LED_COLOR_OFF);
}
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

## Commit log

2025-01-16 main.cpp変更
2025-01-22 心拍と筋電位の関数，追加
2025-03-07 edit readme
    [controllerV2.kicad_pcb, controllerV2.kicad_sch, tape-tics_projectV2.kicad_pcb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]
